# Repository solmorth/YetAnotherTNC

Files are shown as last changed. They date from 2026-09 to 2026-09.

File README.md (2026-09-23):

# YetAnotherTNC

Zephyr firmware (and, eventually, a companion PCB) for a nRF52840 Pro Micro
board that turns a phone's Bluetooth connection into a packet radio TNC.
Depending on how three GPIO pins are strapped at boot, the board acts as a
transparent UART↔BLE bridge, a real AX.25/KISS TNC driving 1200 baud Bell 202
AFSK audio (with optional FX.25 FEC), an AX.25 digipeater, or a standalone GPS
APRS tracker that beacons its position with no phone attached.

> **Early stage.** This has not been widely field-tested — one unit rides in
> the author's car and works there, but it hasn't been validated across
> different radios, conditions, or by other users. Treat it as a hobby
> project that works, not a hardened product.

No app or phone-side code lives in this repo — this is the board (and PCB)
side only. Anything that speaks BLE Nordic UART Service (NUS) and either raw
KISS or TNC2 monitor lines can talk to it; see [Phone app](#phone-app) below.

## Contents

- [Why](#why)
- [Hardware](#hardware)
  - [PCB](#pcb)
  - [Pinout](#pinout)
  - [Transceiver connector (JST 10-pin)](#transceiver-connector-jst-10-pin)
  - [Bill of Materials (BOM)](#bill-of-materials-bom)
- [Operating modes](#operating-modes)
- [Runtime configuration](#runtime-configuration)
- [Known limitations](#known-limitations)
- [Phone app](#phone-app)
- [Building](#building)
  - [Releases](#releases)
- [Testing](#testing)
- [Hardware-in-the-loop (HIL) test plan](#hardware-in-the-loop-hil-test-plan)
- [Repo layout](#repo-layout)
- [License](#license)

## Why

Cheap handheld radios generally don't have a KISS/TNC mode, and dedicated TNC
hardware is either bulky or costs more than the radio. This is a ~$10 nRF52840
board wired to a radio's mic/speaker/PTT lines, doing the AFSK modem and
AX.25 framing in software, with a phone or laptop over BLE instead of a serial
cable.

## Hardware

**Primary target: Yaesu FTM510.** The board's connector is designed to match
the FTM510's mic/data jack. The **FTM400 works out of the box** — same
connector, same signals. Any other radio that can be driven by its
mic/speaker/PTT lines can work too, via a custom audio interface cable
(not covered by this repo — just the pins on the nRF52840 side).

Board: Pro Micro nRF52840 (or any nice!nano-bootloader-compatible clone,
`promicro_nrf52840` in Zephyr).

### PCB

PCB design files and bill of materials live under [`pcb/`](pcb/) (`yatnc.kicad_sch`, `yatnc.kicad_pcb`, `yatnc.csv`).

| PCB 3D Render | PCB Editor |
|:---:|:---:|
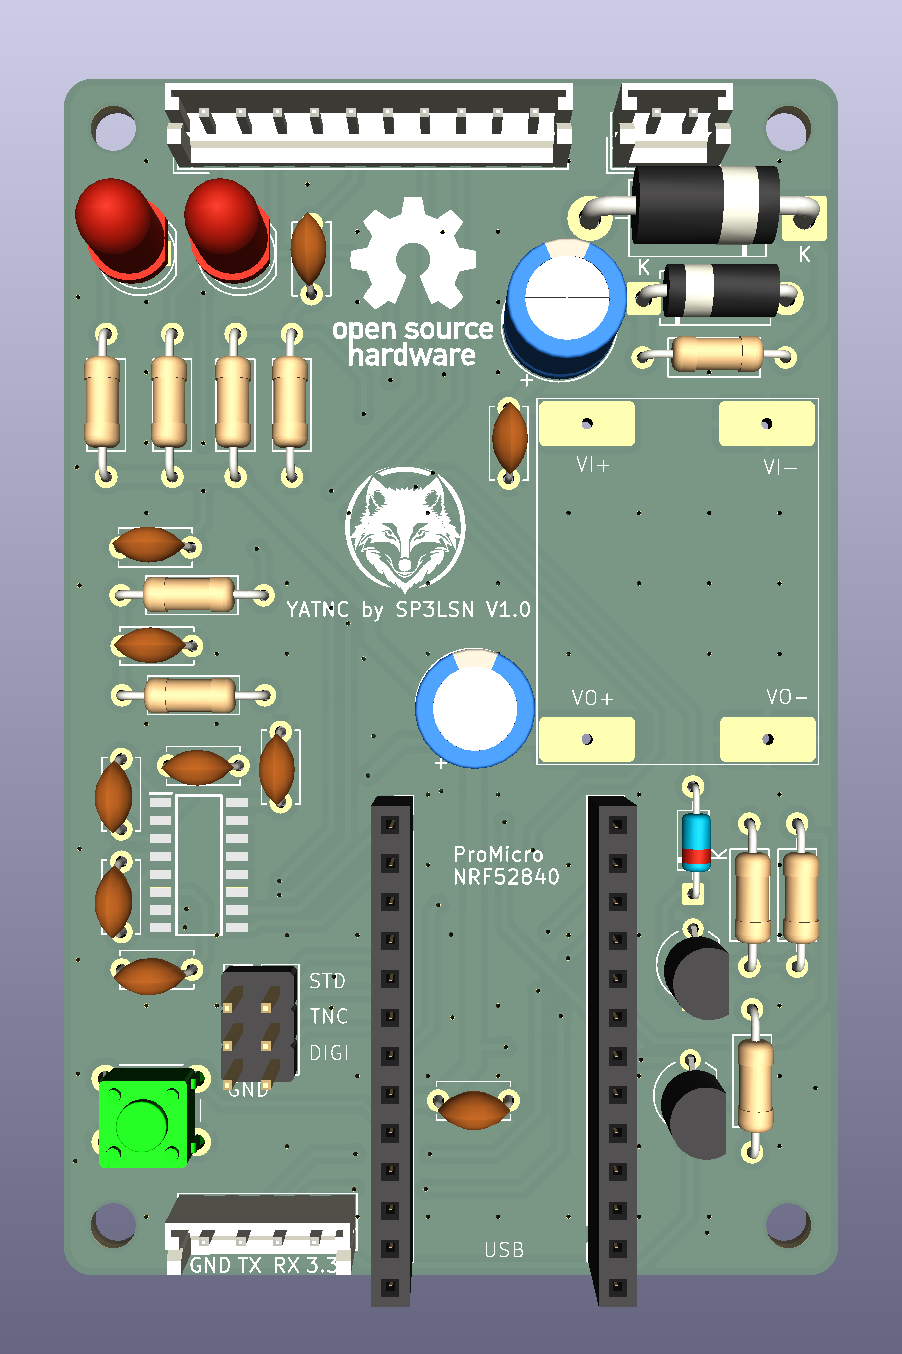
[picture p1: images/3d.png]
PCB 3D Render
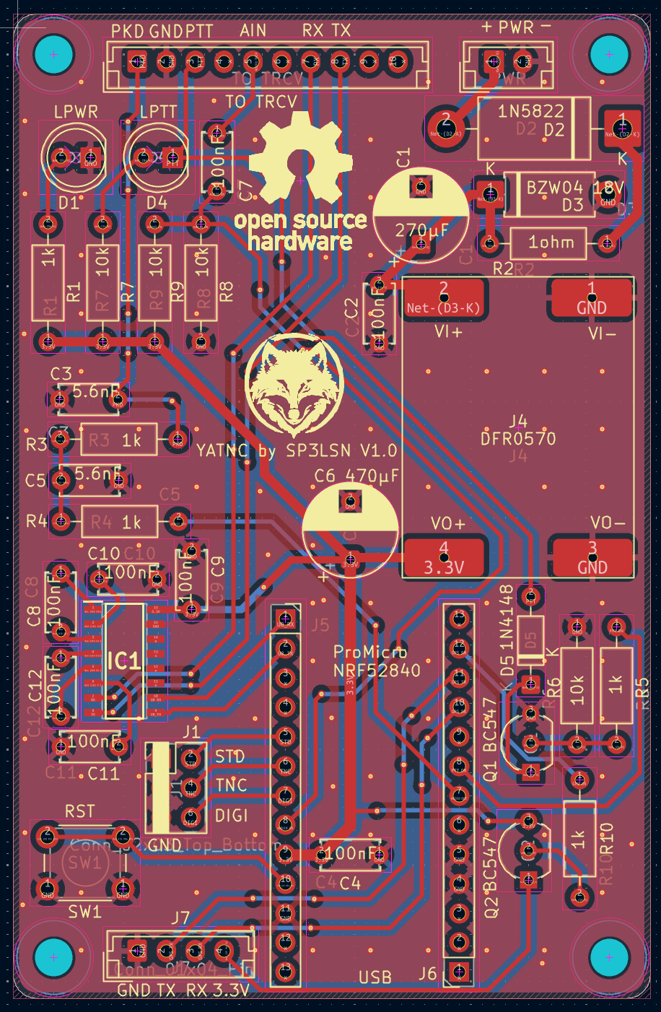
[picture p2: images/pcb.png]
PCB Editor
|  |  |

### Pinout

| Pin | DT node | Function | Notes |
|---|---|---|---|
| 9, 10 (P0.09/P0.10) | `uart0` | Radio RS232 (APRS data) | Level-shifted through an onboard MAX3232 to true RS-232 (±12V). Primary use: the FTM510/FTM400's own built-in APRS packet decoder outputs RS232 here in BRIDGE mode. Also works with other serial-speaking radios/modems that expect a native protocol. Never touched by firmware for anything else. |
| 31 (P0.31) | `zephyr,user` io-channel | RX audio in | ADC (AIN7), sampled at 9600 Hz for the AFSK demodulator. |
| 20 (P0.20) | `&pwm0_default` | TX audio out | Hardware PWM carrier, low-pass filtered externally into an analog tone. |
| 22 (P0.22) | `ptt_pin` | PTT out | Active-high. |
| 2 (P0.02) | `mode_pin` | Mode select | Pull-up, active-low. Grounded → PACKET_TNC. |
| 29 (P0.29) | `digi_pin` | Digipeater select | Pull-up, active-low. Grounded → DIGIPEATER (overrides pin 2). |
| P1.15 | `standalone_pin` | Standalone GPS select | Pull-up, active-low. Grounded → STANDALONE (overrides pins 2 and 29). |
| P0.11 / P1.00 | `uart1` | GPS NMEA in | 9600 baud, TX / RX respectively (the GPS module's RX / TX). Only used in STANDALONE mode. |
| P1.04 | `gps_enable_pin` | GPS power enable | Active-high, pulled down. Driven high at boot in STANDALONE mode (unless a fixed position is configured). |

### Transceiver connector (JST 10-pin)

> [!IMPORTANT]
> - **RS-232 voltage levels (±12V)**: The serial lines on the 10-pin JST connector (`TO TRCV`) are true **RS-232 (±12V)** driven by the onboard MAX3232 transceiver, **not** 3.3V or 5V TTL. Do not connect them directly to logic-level UART pins!
> - **RX / TX crossover**: The RS-232 RX and TX lines **must be crossed** between the board's 10-pin JST connector and the radio (Board TX &rarr; Radio RX, Board RX &rarr; Radio TX).

| Pin | Net | Function / Description |
|:---:|---|---|
| 1 | `PKD` | TX Packet Audio (from PWM filter) |
| 2 | `GND` | Ground |
| 3 | `PTT` | PTT output |
| 4 | NC | Unconnected |
| 5 | `AUDIO TRCV` | RX Audio (to ADC demodulator) |
| 6 | NC | Unconnected |
| 7 | `RX` | RS-232 RX (±12V, connect to Radio TX — **crossed**) |
| 8 | `TX` | RS-232 TX (±12V, connect to Radio RX — **crossed**) |
| 9 | NC | Unconnected |
| 10 | NC | Unconnected |

### Bill of Materials (BOM)

Generated from KiCad BOM ([`pcb/yatnc.csv`](pcb/yatnc.csv)):

| Designator | Value / Part | Qty | Description |
|---|---|:---:|---|
| C1 | 270µF 35V | 1 | Polarized electrolytic capacitor |
| C2, C4, C7, C8, C9, C10, C11, C12 | 100nF | 8 | Ceramic disc capacitor |
| C3, C5 | 5.6nF | 2 | Ceramic disc capacitor |
| C6 | 470µF 10V | 1 | Polarized electrolytic capacitor |
| D1 | LPWR | 1 | Power indicator LED (5mm) |
| D2 | 1N5822 | 1 | Schottky diode (3A, 40V) |
| D3 | BZW04 18V | 1 | TVS transient voltage suppressor diode |
| D4 | LPTT | 1 | PTT indicator LED (5mm) |
| D5 | 1N4148 | 1 | High-speed switching diode |
| IC1 | MAX3232CDR | 1 | 3.3V/5V RS-232 transceiver (SOIC-16) |
| J1 | Conn_02x03_Top_Bottom | 1 | 2×3 pin header (2.54mm pitch) |
| J4 | DFR0570 | 1 | DFRobot DFR0570 DC-DC buck converter module |
| J5, J6 | Conn_01x13_Socket | 2 | 1×13 female socket headers (for Pro Micro nRF52840) |
| J7 | Conn_01x04_Pin | 1 | JST-EH 4-pin vertical header (2.50mm pitch) |
| PWR | Conn_01x02_Socket | 1 | JST-EH 2-pin vertical power connector (2.50mm pitch) |
| Q1, Q2 | BC547 | 2 | NPN bipolar junction transistor (TO-92) |
| R1, R3, R4, R5, R10 | 1k | 5 | Axial resistor 1kΩ (DIN0207) |
| R2 | 1ohm | 1 | Axial resistor 1Ω (DIN0207) |
| R6, R7, R8, R9 | 10k | 4 | Axial resistor 10kΩ (DIN0207) |
| SW1 | RST | 1 | Tactile push button switch (6mm) |
| TO TRCV | JST | 1 | JST-EH 10-pin vertical connector (to transceiver) |

### Transceiver connector (JST 10-pin)

> [!IMPORTANT]
> - **RS-232 voltage levels (±12V)**: The serial lines on the 10-pin JST connector (`TO TRCV`) are true **RS-232 (±12V)** driven by the onboard MAX3232 transceiver, **not** 3.3V or 5V TTL. Do not connect them directly to logic-level UART pins!
> - **RX / TX crossover**: The RS-232 RX and TX lines **must be crossed** between the board's 10-pin JST connector and the radio (Board TX &rarr; Radio RX, Board RX &rarr; Radio TX).

| Pin | Net | Function / Description |
|:---:|---|---|
| 1 | `PKD` | TX Packet Audio (from PWM filter) |
| 2 | `GND` | Ground |
| 3 | `PTT` | PTT output |
| 4 | NC | Unconnected |
| 5 | `AUDIO TRCV` | RX Audio (to ADC demodulator) |
| 6 | NC | Unconnected |
| 7 | `RX` | RS-232 RX (±12V, connect to Radio TX — **crossed**) |
| 8 | `TX` | RS-232 TX (±12V, connect to Radio RX — **crossed**) |
| 9 | NC | Unconnected |
| 10 | NC | Unconnected |

### Bill of Materials (BOM)

Generated from KiCad BOM ([`pcb/yatnc.csv`](pcb/yatnc.csv)):

| Designator | Value / Part | Qty | Description |
|---|---|:---:|---|
| C1 | 270µF 35V | 1 | Polarized electrolytic capacitor |
| C2, C4, C7, C8, C9, C10, C11, C12 | 100nF | 8 | Ceramic disc capacitor |
| C3, C5 | 5.6nF | 2 | Ceramic disc capacitor |
| C6 | 470µF 10V | 1 | Polarized electrolytic capacitor |
| D1 | LPWR | 1 | Power indicator LED (5mm) |
| D2 | 1N5822 | 1 | Schottky diode (3A, 40V) |
| D3 | BZW04 18V | 1 | TVS transient voltage suppressor diode |
| D4 | LPTT | 1 | PTT indicator LED (5mm) |
| D5 | 1N4148 | 1 | High-speed switching diode |
| IC1 | MAX3232CDR | 1 | 3.3V/5V RS-232 transceiver (SOIC-16) |
| J1 | Conn_02x03_Top_Bottom | 1 | 2×3 pin header (2.54mm pitch) |
| J4 | DFR0570 | 1 | DFRobot DFR0570 DC-DC buck converter module |
| J5, J6 | Conn_01x13_Socket | 2 | 1×13 female socket headers (for Pro Micro nRF52840) |
| J7 | Conn_01x04_Pin | 1 | JST-EH 4-pin vertical header (2.50mm pitch) |
| PWR | Conn_01x02_Socket | 1 | JST-EH 2-pin vertical power connector (2.50mm pitch) |
| Q1, Q2 | BC547 | 2 | NPN bipolar junction transistor (TO-92) |
| R1, R3, R4, R5, R10 | 1k | 5 | Axial resistor 1kΩ (DIN0207) |
| R2 | 1ohm | 1 | Axial resistor 1Ω (DIN0207) |
| R6, R7, R8, R9 | 10k | 4 | Axial resistor 10kΩ (DIN0207) |
| SW1 | RST | 1 | Tactile push button switch (6mm) |
| TO TRCV | JST | 1 | JST-EH 10-pin vertical connector (to transceiver) |

## Operating modes

The firmware selects one of four modes at boot (and re-checks live on every
packet) by reading the mode-select, digipeater-select and standalone-select pins above. There is
no software switch — the mode is purely hardware-strapped, and the pins are
read fresh on every packet, so mode can in principle change at runtime by
re-wiring the straps (no latching).

Resolution order (`mode_select_get_current()` in `src/mode_select.c`):

1. `standalone_pin` grounded → **STANDALONE**
2. else `digi_pin` grounded → **DIGIPEATER**
3. else `mode_pin` grounded → **PACKET_TNC**
4. else (all floating/high, the default) → **BRIDGE**

### 1. BRIDGE (default — all pins open)

A transparent, byte-for-byte serial bridge between the radio's RS232 (UART0)
and the phone app over BLE (NUS). No AX.25/KISS parsing, no AFSK, no PTT —
just raw bytes both directions.

This is primarily for **FTM510/FTM400 radios in their own native APRS
mode**: the radio decodes AFSK itself and emits packets over RS232, and this
mode just relays that (and any outgoing data) to/from the phone app. It also
works with any other radio/modem that expects to speak its own native serial
protocol (AT commands, firmware passthrough, etc.) rather than doing AX.25
packet radio in this firmware.

- **Radio → App**: `uart_isr` (main.c) collects UART0 RX bytes into a ring
  buffer; 50ms after the line goes idle, `process_uart_to_ble()` sends
  whatever accumulated straight out over BLE notify.
- **App → Radio**: `nus_received()` queues whatever the app wrote straight to
  the TX queue; the TX thread writes it byte-by-byte to UART0 via
  `uart_poll_out()`.

### 2. PACKET_TNC (`mode_pin` grounded)

A real AX.25 KISS TNC. The app talks AX.25/KISS over BLE; the radio side is
driven as 1200 baud Bell 202 AFSK audio (with optional FX.25 forward error
correction), not raw serial.

**App → Radio (TX)**, in `tnc_process_ble_bytes()`:

1. Bytes from BLE are fed into a persistent KISS decoder. A full KISS frame
   (`FEND ... FEND`) is only acted on once its closing `FEND` has actually
   arrived — a frame split across several BLE writes (common: phones write
   in ~20-byte ATT chunks before MTU negotiation) is reassembled correctly
   before anything is sent.
2. Most phone APRS apps don't actually KISS-frame anything — they write a
   human-readable **TNC2 monitor line** instead, e.g.
   `SP3LSN-9>APVEC0,WIDE1-1,WIDE2-1:!5227.76N/01654.03E>comment`. If nothing
   KISS-decodes within 250ms of the app going idle, `tnc_send_raw_frame()`
   tries `ax25_parse_monitor()` on the accumulated bytes; on success it
   builds a real binary AX.25 UI frame (proper shifted-ASCII addresses,
   control/PID, FCS) instead of transmitting the raw text. If it doesn't
   parse either way, the bytes are assumed to already be a raw AX.25 frame
   and sent as-is.
3. If a stray `FEND` byte appears in non-KISS app data (e.g. a Latin-1
   accented character in an APRS comment happens to be `0xC0`) and never
   gets a matching closing `FEND`, the KISS decoder used to wedge itself
   in-frame forever, silently swallowing everything after it. It now
   self-resets after the same 250ms idle window instead.
4. Every queued frame is picked up by the TX thread: PTT keys (pin 22,
   active-high), the frame is modulated to AFSK PCM (`AFSKModulator`, with
   FX.25 RS(255,239) wrapping if enabled via `audio_tx_set_fx25(true)` —
   off by default, no live control path wired to it yet), the waveform is
   played out on pin 20 via the nRF52840's hardware PWM, then PTT unkeys.

**Radio → App (RX)**, two independent sources feed the same BLE output:

- **Audio demodulation**: a dedicated thread samples pin 31 (ADC, AIN7) at
  9600Hz through `AFSKDemodulator` (bandpass filter → frequency discriminator
  → DPLL bit recovery → HDLC flag/destuff, with an FX.25 correlation-tag
  correlator running in parallel that transparently Reed-Solomon-corrects a
  frame if the sender wrapped it in FX.25). A decoded frame is KISS-wrapped
  and sent over BLE.
- **UART0**: if the radio/modem itself emits KISS bytes over serial rather
  than raw audio, `tnc_process_radio_bytes()` decodes and forwards those the
  same way.

### 3. DIGIPEATER (`digi_pin` grounded, overrides `mode_pin`)

Everything PACKET_TNC does, plus: every frame heard on the radio is checked
for an un-repeated `WIDEn-N`/`DIGI` hop in its path
(`digipeat_process_frame()`). If found, the hop's SSID is decremented (H-bit
set once it reaches 0, marking it used) and the frame is re-encoded and
re-transmitted back out over radio — a standard WIDEn-N digipeater. The frame
is forwarded to the BLE app either way, repeated or not, so the app sees
everything heard on the channel.

### 4. STANDALONE (`standalone_pin` grounded, overrides the other two)

A GPS APRS tracker. The board beacons its position over the radio on a timer,
with no phone needed. Otherwise it behaves like PACKET_TNC (the BLE app can
still connect, send frames, and change [settings](#runtime-configuration)).

- **Live GPS** (default): at boot the firmware powers the GPS module
  (`gps_enable_pin`) and reads NMEA from `uart1`. `$GPGGA`/`$GNGGA` sentences
  are parsed for fix state and position. The first fix starts the beacon; it
  then repeats every `BEACON` seconds while the fix is held, using the most
  recent position. No fix (or fix lost) → nothing is transmitted.
- **Fixed position**: with `SET FIXEDPOS=ON` (and both `LAT`/`LON` set) the
  GPS module is never powered or touched. The stored coordinates are beaconed
  on the same interval, starting once the TX pipeline is up. Handy indoors or
  with no GPS fitted. Until both coordinates are set, nothing is sent.
- **Beacon format**: an uncompressed APRS position report (`!DDMM.hhN/DDDMM.hhE>` + comment)
  from your callsign to `APRS`, primary-table car symbol (`/>`), sent through the
  normal TX path (PTT → AFSK → PWM).

## Runtime configuration

Callsign, beacon interval, comment and fixed position are set at runtime with
single-line ASCII commands sent as KISS command `0x06` (`KISS_CMD_SETHARDWARE`)
over BLE. Each command is applied immediately, saved to flash, and answered
with a KISS `0x06` frame carrying the reply text. Errors are reported in the
reply (`ERR ...`), never as a dropped connection. Settings survive reboots.

| Command | Effect | Default |
|---|---|---|
| `SET CALL=N0CALL-9` | Source callsign for beacons | `N0CALL` |
| `SET BEACON=120` | Beacon interval in seconds (clamped to 10–3600) | `60` |
| `SET COMMENT=text` | Beacon comment (truncated to 32 chars) | empty |
| `SET FIXEDPOS=ON\|OFF` | Beacon a stored position instead of using GPS | `OFF` |
| `SET LAT=52.4627` / `SET LON=16.9005` | Fixed position, decimal degrees | unset |
| `GET` | Reply with all current values | |

The settings live in a 32 KiB NVS partition at `0x90000` (see `app.overlay`),
deliberately clear of the UF2 bootloader. The BLE device name is `YATNC`.

## Known limitations

- **AFSK decode is functional but not polished.** It works, but weak-signal
  / low-level decode robustness needs more work — expect some missed frames
  on marginal audio until the demodulator gets more tuning.
- **Not widely field-tested.** Verified on the bench and in one car; not yet
  validated across multiple radios, RF conditions, or users.
- FX.25 TX wrapping has no live control path yet (`audio_tx_set_fx25`, code
  only).
- STANDALONE mode parses GGA sentences only, with no altitude, speed/course or
  compressed positions in the beacon. The symbol is fixed to the car icon.
- The `SET`/`GET` config commands are not yet exposed in any phone app; send
  them yourself as KISS `0x06` frames.

## Phone app

Developed and tested against **[aprsvector](https://aprsvector.ores.one)**
(also by the author) — that's the reference app for this firmware and the
one to reach for first.

More generally, anything that speaks BLE Nordic UART Service (NUS) and
either raw KISS or TNC2 monitor lines *should* work (most Android APRS apps
fit this description), but only aprsvector has actually been tested against
this firmware.

## Building

```sh
./build.sh
```

First run creates a `.venv`, pulls a Zephyr workspace into `zephyrproject/`
(via `west`), and builds for `promicro_nrf52840`. Later runs reuse both, so
they're much faster. Pass anything after the script name straight through to
`west build` if you need non-default args:

```sh
./build.sh -b promicro_nrf52840 --pristine
```

If no usable Zephyr SDK is found (it looks in `.zephyr-sdk/`,
`~/zephyr-sdk-*`, `/opt/zephyr-sdk-*`, etc, and checks that CMake and the ARM
compiler are actually present), the script downloads a minimal one into
`.zephyr-sdk/` and sets up the `arm-zephyr-eabi` toolchain. Set
`ZEPHYR_SDK_INSTALL_DIR` to use your own instead.

Output is `build/zephyr/zephyr.uf2`. To flash: double-tap the board's reset
button to drop into the UF2 bootloader (it'll show up as a USB drive), then
copy the file over. Boards need the nice!nano / Adafruit UF2 bootloader
already installed.

### Releases

Pushing a version tag (`1.2.3` or `v1.2.3`) triggers
`.github/workflows/release.yml`, which runs the host tests, builds the
firmware, and publishes a GitHub release with `yatnc-<tag>.uf2` attached, so
you can flash without building.

```sh
git tag 1.2.3 && git push origin 1.2.3
```

## Testing

```sh
./run_tests.sh
```

Builds and runs the host-side unit tests for everything that doesn't touch
Zephyr or real hardware — AX.25, KISS, FX.25, GPS/NMEA formatting, and the AFSK modem DSP — and
fails if line coverage on any of those drops below 80%. `tnc.c`, `main.c`,
`ptt.c`, `mode_select.c`, `gps.c`, `tnc_config.c`, and the audio drivers aren't covered here; they need
a board, see [HIL test plan](#hardware-in-the-loop-hil-test-plan).

There's also a Python reference model of the AFSK modem
(`tools/afsk_dsp.py`, tested by `tools/test_afsk.py`/`pytest`) used to
sanity-check the C++ implementation and to generate/analyze WAV captures
independent of the firmware.

## Hardware-in-the-loop (HIL) test plan

`run_tests.sh` covers the Zephyr-free pure-logic modules (AX.25, KISS, FX.25,
GPS formatting, AFSK modem DSP) at ≥80% line coverage on host. It cannot touch anything that
only exists on real silicon: GPIO strapping, hardware PWM audio out, ADC
audio in, UART timing, or BLE NUS. Those need the actual `promicro_nrf52840`
board. This is a plan, not a runnable suite yet — no board rig is set up for
automated HIL runs.

What each untestable-on-host module needs:

1. **`mode_select.c`** — ground/float P0.02, P0.29 and P1.15 in each
   combination, reboot, confirm `mode_select_get_current()`/boot log report
   BRIDGE / PACKET_TNC / DIGIPEATER / STANDALONE correctly, and that re-strapping is
   picked up live (no latching).
2. **`ptt.c`** — scope P0.22 across a TX; confirm it goes active-high only
   for the duration `audio_tx_pwm` is actually playing samples, and idles
   low the rest of the time (a PTT stuck high keys the radio permanently).
3. **`audio_tx_pwm.cpp`** — scope P0.20; confirm the PWM carrier frequency
   and the external low-pass filter actually pass 1200/2200 Hz clean and
   knock the PWM carrier down enough that an external TNC (or this board's
   own RX path, looped back) decodes it.
4. **`audio_rx_adc.cpp`** — feed a known AFSK signal into P0.31 (from a
   signal generator, or TX pin of a second unit looped back through the
   filter) and confirm frames make it out over BLE.
5. **RS232 bridge (BRIDGE mode, `main.c`)** — with a real FTM510/FTM400 (or
   other serial device) on P0.09/P0.10 through the onboard MAX3232, confirm
   byte-for-byte passthrough both directions and the 50ms idle-flush timing.
6. **BLE NUS end-to-end** — a phone/PC BLE client sends a KISS frame or
   TNC2 monitor line; confirm it comes out the radio side per the routing
   already unit-tested at the `ax25.c`/`kiss.c` level, and vice versa.
7. **`gps.c`** — in STANDALONE mode with a GPS module on P0.11/P1.00, confirm
   P1.04 goes high at boot, NMEA shows in the log, and a beacon goes out
   after the first fix and again every `BEACON` seconds. With
   `FIXEDPOS=ON`, confirm P1.04 stays low and the stored position beacons.
8. **`tnc_config.c`** — send each `SET`/`GET` command over BLE, confirm the
   reply, power-cycle, and confirm values persist. Confirm the UF2 bootloader
   still works afterwards (NVS must not touch it).
9. **Full loop**: two boards, one PACKET_TNC and one DIGIPEATER, over actual
   RF or a dummy-load/attenuator link — confirms the whole AFSK+FX.25+KISS
   stack end to end, not just each half in isolation on host.

Implementing an automated HIL rig (e.g. Zephyr `twister --hardware-map`) is a
follow-up once there's dedicated bench hardware for it; for now these are run
by hand.

## Repo layout

```
src/            firmware source (Zephyr app)
tools/          host-side Python tooling (AFSK reference model, WAV decoder, log capture)
app.overlay     devicetree overlay: GPIO straps, GPS UART/enable, ADC channel, PWM pin, NVS partition
prj.conf        Zephyr/Kconfig options
CMakeLists.txt  build target sources
build.sh        one-shot Zephyr workspace + SDK + build
run_tests.sh    host-side unit tests + coverage
.github/        CI: tag-triggered release workflow
gerber/         PCB fabrication files
pcb/            KiCad board design files and BOM (yatnc.kicad_sch, yatnc.kicad_pcb, yatnc.csv)
images/         PCB 3D render and layout editor screenshots
```

Other tools in `tools/`:

- `decode_aprs.py` — decodes AX.25/APRS frames out of a captured WAV file, for checking a TX recording without a second TNC.
- `capture_log.ps1` — tails the board's USB serial console to a timestamped log file, reconnecting automatically across board resets (handy for catching a crash dump).

## License

`src/main.c` carries an `SPDX-License-Identifier: Apache-2.0` header; treat
the rest of the firmware the same way unless noted otherwise.

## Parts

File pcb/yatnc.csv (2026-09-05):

Id | Designator | Footprint | Quantity | Designation | Supplier and ref
1 | C1 | CP_Radial_D8.0mm_P5.00mm | 1 | 270µF
2 | C2, C4, C7, C8, C9, C10, C11, C12 | C_Disc_D5.0mm_W2.5mm_P5.00mm | 8 | 100nF
3 | C3, C5 | C_Disc_D5.0mm_W2.5mm_P5.00mm | 2 | 5.6nF
4 | C6 | CP_Radial_D8.0mm_P5.00mm | 1 | 470µF
5 | D1 | LED_D5.0mm | 1 | LPWR
6 | D2 | D_DO-201AD_P15.24mm_Horizontal | 1 | 1N5822
7 | D3 | D_DO-15_P10.16mm_Horizontal | 1 | BZW04 18V
8 | D4 | LED_D5.0mm | 1 | LPTT
9 | D5 | D_DO-35_SOD27_P7.62mm_Horizontal | 1 | 1N4148
10 | IC1 | SOIC127P600X175-16N | 1 | MAX3232CDR
11 | J1 | PinHeader_2x03_P2.54mm_Vertical | 1 | Conn_02x03_Top_Bottom
12 | J4 | dfr0570 | 1 | DFR0570
13 | J5, J6 | PinSocket_1x13_P2.54mm_Vertical | 2 | Conn_01x13_Socket
14 | J7 | JST_EH_B4B-EH-A_1x04_P2.50mm_Vertical | 1 | Conn_01x04_Pin
15 | PWR | JST_EH_B2B-EH-A_1x02_P2.50mm_Vertical | 1 | Conn_01x02_Socket
16 | Q1, Q2 | TO-92_Inline_Wide | 2 | BC547
17 | R1, R3, R4, R5, R10 | R_Axial_DIN0207_L6.3mm_D2.5mm_P10.16mm_Horizontal | 5 | 1k
18 | R2 | R_Axial_DIN0207_L6.3mm_D2.5mm_P10.16mm_Horizontal | 1 | 1ohm
19 | R6, R7, R8, R9 | R_Axial_DIN0207_L6.3mm_D2.5mm_P10.16mm_Horizontal | 4 | 10k
20 | SW1 | SW_PUSH_6mm | 1 | RST
21 | TO TRCV | JST_EH_B10B-EH-A_1x10_P2.50mm_Vertical | 1 | JST

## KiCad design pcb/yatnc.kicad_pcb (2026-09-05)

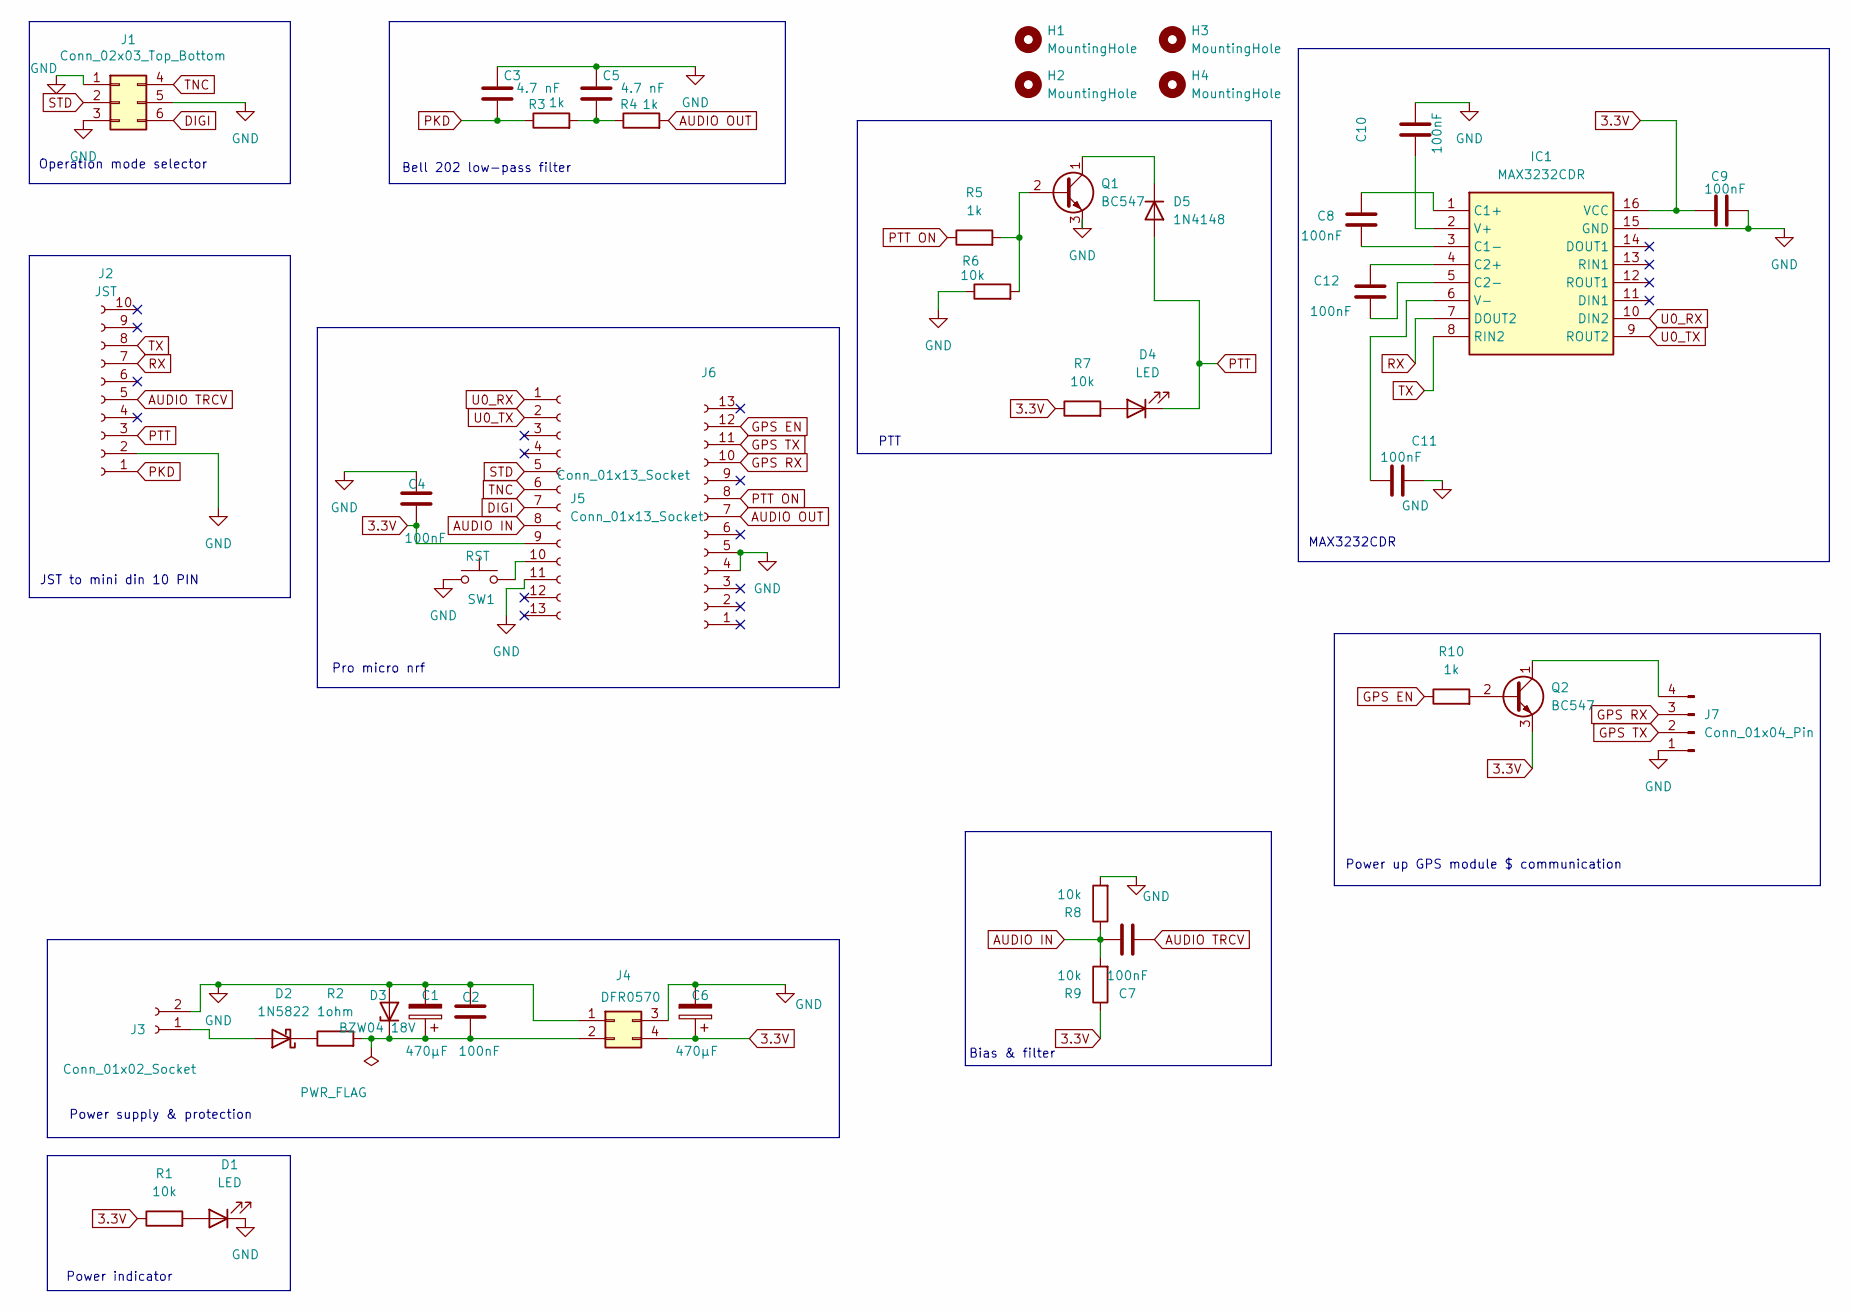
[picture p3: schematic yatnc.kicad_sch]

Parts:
C1, C6: 470µF; CP_Radial_D8.0mm_P5.00mm
C2, C4, C7, C8, C9, C10, C11, C12: 100nF; C_Disc_D5.0mm_W2.5mm_P5.00mm
C3, C5: 4.7 nF; C_Disc_D5.0mm_W2.5mm_P5.00mm
D1, D4: LED; LED_D5.0mm
D2: 1N5822; D_DO-201AD_P15.24mm_Horizontal
D3: BZW04 18V; D_DO-15_P10.16mm_Horizontal
D5: 1N4148; D_DO-35_SOD27_P7.62mm_Horizontal
H1, H2, H3, H4: MountingHole; MountingHole_3.2mm_M3
IC1: MAX3232CDR; SOIC127P600X175-16N; Mouser Part Number 595-MAX3232CDR
J1: Conn_02x03_Top_Bottom; PinHeader_2x03_P2.54mm_Vertical
J2: JST; JST_EH_B10B-EH-A_1x10_P2.50mm_Vertical
J3: Conn_01x02_Socket; JST_EH_B2B-EH-A_1x02_P2.50mm_Vertical
J4: DFR0570; dfr0570
J5, J6: Conn_01x13_Socket; PinSocket_1x13_P2.54mm_Vertical
J7: Conn_01x04_Pin; JST_EH_B4B-EH-A_1x04_P2.50mm_Vertical
Q1, Q2: BC547; TO-92_Inline_Wide
R1, R6, R7, R8, R9: 10k; R_Axial_DIN0207_L6.3mm_D2.5mm_P10.16mm_Horizontal
R2: 1ohm; R_Axial_DIN0207_L6.3mm_D2.5mm_P10.16mm_Horizontal
R3, R4, R5, R10: 1k; R_Axial_DIN0207_L6.3mm_D2.5mm_P10.16mm_Horizontal
SW1: RST; SW_PUSH_6mm

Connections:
3.3V: C4.2, C6.1, C9.1, IC1.16 (VCC), J4.4, J5.9, Q2.3 (E), R1.1, R7.1, R9.1
AUDIO IN: C7.2, J5.8, R8.1, R9.2
AUDIO OUT: J6.7, R4.2
AUDIO TRCV: C7.1, J2.5; also elsewhere on the board
DIGI: J1.6, J5.7
GND: C1.2, C2.1, C3.1, C4.1, C5.1, C6.2, C9.2, C10.2, C11.1, D1.1 (K), D3.2 (A), IC1.15 (GND), J1.1, J1.3, J1.5, J2.2, J3.2, J4.1, J4.3, J5.11, J6.4, J6.5, J7.1, Q1.3 (E), R6.1, R8.2, SW1.1; also elsewhere on the board
GPS EN: J6.12, R10.1
GPS RX: J6.10, J7.3
GPS TX: J6.11, J7.2
unnamed: C5.2, R3.2, R4.1
unnamed: D1.2 (A), R1.2
unnamed 11: D2.2 (A), J3.1; also elsewhere on the board
unnamed: D2.1 (K), R2.1
unnamed: C1.1, C2.2, D3.1 (K), J4.2, R2.2
unnamed: D4.2 (A), R7.2
unnamed: D5.1 (K), Q1.1 (C)
unnamed: C8.1, IC1.1 (C1+)
unnamed: C8.2, IC1.3 (C1-)
unnamed: C12.1, IC1.4 (C2+)
unnamed: C12.2, IC1.5 (C2-)
unnamed: C10.1, IC1.2 (V+)
unnamed: C11.2, IC1.6 (V-)
unnamed: J5.10, SW1.2
unnamed: J7.4, Q2.1 (C)
unnamed: Q1.2 (B), R5.2, R6.2
unnamed: Q2.2 (B), R10.2
PKD: C3.2, J2.1, R3.1; also elsewhere on the board
PTT: D4.1 (K), D5.2 (A), J2.3; also elsewhere on the board
PTT ON: J6.8, R5.1
RX: IC1.7 (DOUT2), J2.7; also elsewhere on the board
STD: J1.2, J5.5
TNC: J1.4, J5.6
TX: IC1.8 (RIN2), J2.8; also elsewhere on the board
U0_RX: IC1.10 (DIN2), J5.1
U0_TX: IC1.9 (ROUT2), J5.2

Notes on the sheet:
MAX3232CDR
Operation mode selector
Power up GPS module $ communication
Power supply & protection
Bias & filter
Power indicator
JST to mini din 10 PIN
PTT
Bell 202 low-pass filter
Pro micro nrf

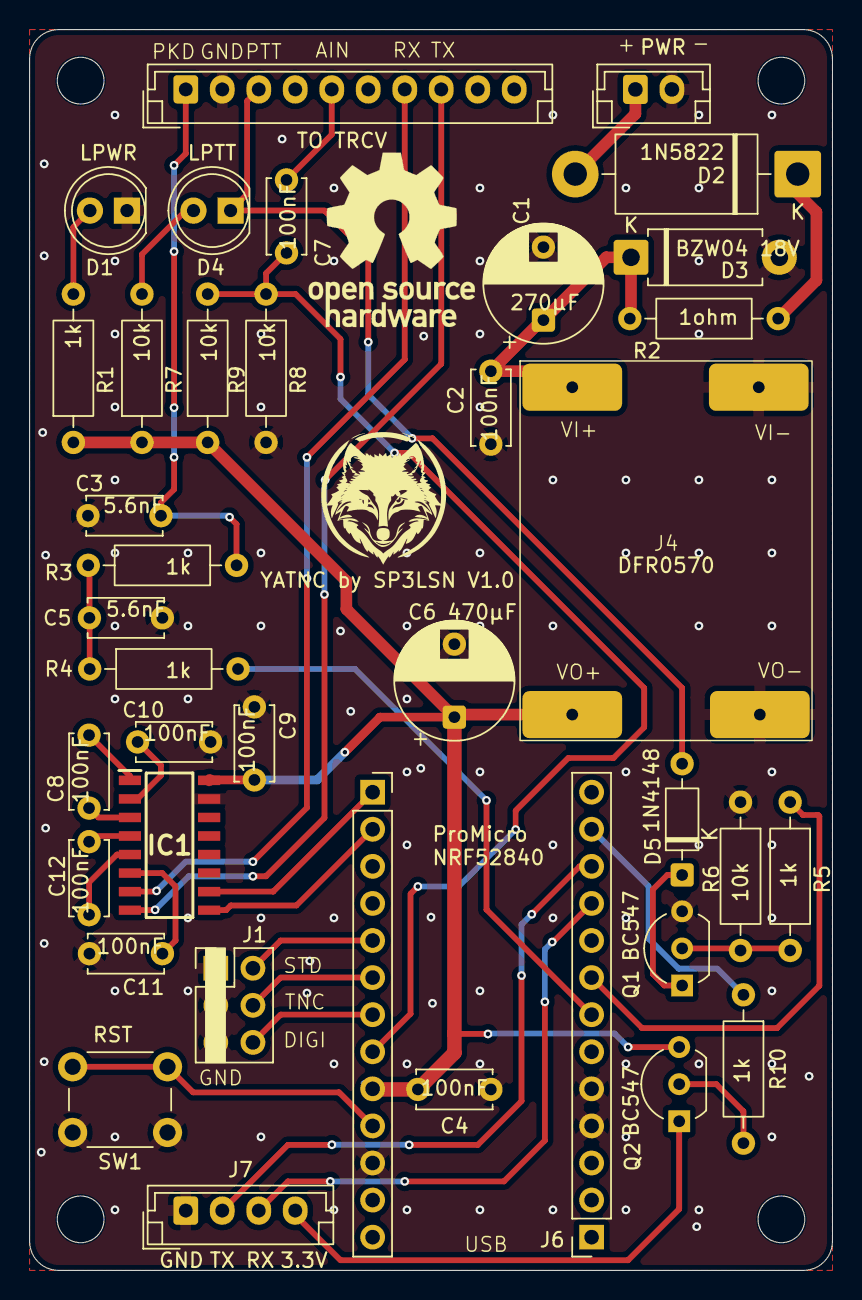
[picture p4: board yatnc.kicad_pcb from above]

Board: 2 copper layers, 55.0 x 85.0 mm, 42 parts (0 on the bottom side), 35 nets.

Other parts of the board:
PWR: Conn_01x02_Socket; JST_EH_B2B-EH-A_1x02_P2.50mm_Vertical
TO TRCV: JST; JST_EH_B10B-EH-A_1x10_P2.50mm_Vertical

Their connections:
AUDIO TRCV: TO TRCV.5; also elsewhere on the board
GND: PWR.2, TO TRCV.2; also elsewhere on the board
unnamed 11: PWR.1; also elsewhere on the board
PKD: TO TRCV.1; also elsewhere on the board
PTT: TO TRCV.3; also elsewhere on the board
RX: TO TRCV.7; also elsewhere on the board
TX: TO TRCV.8; also elsewhere on the board

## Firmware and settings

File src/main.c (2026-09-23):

/*
 * UART0 <-> BLE NUS Bridge & APRS TNC Server for ProMicro nRF52840
 *
 * SPDX-License-Identifier: Apache-2.0
 *
 * Uses interrupt-driven UART with a delayed work item for batching.
 * Supports hardware GPIO mode selection:
 *   - APP_MODE_BRIDGE: Transparent UART <-> BLE bridge (Pin High / Unbridged)
 *   - APP_MODE_PACKET_TNC: AX.25 / KISS TNC server (Pin Low / Grounded)
 *   - APP_MODE_DIGIPEATER: AX.25 Digipeater & BLE forwarding (Digi Pin Grounded)
 *
 * Console/printk goes over USB CDC ACM (configured by board DTS).
 */

#include <string.h>
#include <zephyr/kernel.h>
#include <zephyr/device.h>
#include <zephyr/drivers/uart.h>
#include <zephyr/bluetooth/bluetooth.h>
#include <zephyr/bluetooth/conn.h>
#include <zephyr/bluetooth/services/nus.h>
#include <zephyr/sys/ring_buffer.h>
#include <zephyr/version.h>

#include "mode_select.h"
#include "ptt.h"
#include "gps.h"
#include "tnc.h"
#include "ax25.h"
#include "fx25.h"
#include "kiss.h"
#include "tnc_config.h"
#include "audio_tx_pwm.hpp"
#include "audio_rx_adc.hpp"
#include "log_ts.h"

/* ---------- BLE advertising -------------------------------------------- */

#define DEVICE_NAME     CONFIG_BT_DEVICE_NAME
#define DEVICE_NAME_LEN (sizeof(DEVICE_NAME) - 1)

static const struct bt_data ad[] = {
	BT_DATA_BYTES(BT_DATA_FLAGS, (BT_LE_AD_GENERAL | BT_LE_AD_NO_BREDR)),
	BT_DATA(BT_DATA_NAME_COMPLETE, DEVICE_NAME, DEVICE_NAME_LEN),
};

static const struct bt_data sd[] = {
	BT_DATA_BYTES(BT_DATA_UUID128_ALL, BT_UUID_NUS_SRV_VAL),
};

/* ---------- UART ------------------------------------------------------- */

#define UART_NODE DT_CHOSEN(zephyr_nus_uart)
static const struct device *const uart_dev = DEVICE_DT_GET(UART_NODE);

#define RING_BUF_SIZE 1024
RING_BUF_DECLARE(uart_ring_buf, RING_BUF_SIZE);

/*
 * Delayed work: scheduled 50 ms after last received byte.
 * When it fires, the UART line has been idle for 50 ms → full message ready.
 */
static void uart_flush_work_handler(struct k_work *work);
static K_WORK_DELAYABLE_DEFINE(uart_flush_work, uart_flush_work_handler);

#define UART_IDLE_TIMEOUT_MS 50

/* ---------- Forward declarations --------------------------------------- */
static int process_uart_to_ble(void);

/* ---------- UART ISR --------------------------------------------------- */

/* printk() is not IRQ-safe on the USB CDC ACM console backend used here -
 * it can block waiting on the USB stack, which never completes from inside
 * an ISR and freezes the whole system (no fault, no reset, everything
 * including the tick just stops). Count drops here; report them from
 * uart_flush_work_handler() instead, which runs in thread context.
 */
static atomic_t uart_dropped_bytes = ATOMIC_INIT(0);

static void uart_isr(const struct device *dev, void *user_data)
{
	ARG_UNUSED(user_data);

	uart_irq_update(dev);

	if (uart_irq_rx_ready(dev)) {
		uint8_t buf[64];
		int len;

		while ((len = uart_fifo_read(dev, buf, sizeof(buf))) > 0) {
			uint32_t put = ring_buf_put(&uart_ring_buf, buf, len);
			if (put < (uint32_t)len) {
				atomic_add(&uart_dropped_bytes, (atomic_val_t)(len - (int)put));
			}
		}

		/*
		 * (Re)schedule the flush work 50 ms from now.
		 * Batch message when line goes quiet for 50ms.
		 */
		k_work_reschedule(&uart_flush_work, K_MSEC(UART_IDLE_TIMEOUT_MS));
	}
}

/* ---------- Flush work: sends accumulated UART data over BLE ----------- */

static void uart_flush_work_handler(struct k_work *work)
{
	ARG_UNUSED(work);

	atomic_val_t dropped = atomic_set(&uart_dropped_bytes, 0);
	if (dropped) {
		printk("Warning: UART ring buffer full, dropped %d bytes\n", (int)dropped);
	}

	process_uart_to_ble();
}

/*
 * bt_nus_send() -> bt_gatt_notify() -> bt_att_create_pdu() blocks for up to
 * BT_ATT_TIMEOUT (30s, see att.c) when the host's ATT buffer pool is
 * exhausted - i.e. whenever the BLE peer isn't draining notifications as
 * fast as we're producing them. ble_send_raw() is called straight from
 * uart_flush_work_handler on the system workqueue, which is also the only
 * thing draining uart_ring_buf - if it blocks there, UART reception stalls
 * too. Decouple: enqueue here (fast, never blocks) and let a dedicated
 * thread take the blocking hit, same pattern as tx_thread_entry/tx_msgq.
 */
#define BLE_TX_ITEM_MAX_LEN 512
#define BLE_TX_MSGQ_DEPTH 16

struct ble_tx_item {
	uint8_t data[BLE_TX_ITEM_MAX_LEN];
	size_t len;
};

K_MSGQ_DEFINE(ble_tx_msgq, sizeof(struct ble_tx_item), BLE_TX_MSGQ_DEPTH, 4);

/* Ref'd in ble_connected(), unref'd in ble_disconnected() - see below. */
static struct bt_conn *active_conn;

static void ble_tx_thread_entry(void *p1, void *p2, void *p3)
{
	ARG_UNUSED(p1);
	ARG_UNUSED(p2);
	ARG_UNUSED(p3);

	struct ble_tx_item item;
	int consecutive_fail = 0;

	k_thread_name_set(k_current_get(), "ble_tx");

	while (1) {
		k_msgq_get(&ble_tx_msgq, &item, K_FOREVER);

		int err = bt_nus_send(NULL, item.data, item.len);
		if (err) {
			if (err == -ENOTCONN) {
				printk("  (no BLE peer)\n");
				consecutive_fail = 0;
			} else {
				/* bt_att_create_pdu() blocks up to 30s per call when the
				 * peer isn't draining notifications fast enough, then
				 * fails with -ENOMEM - this thread would otherwise grind
				 * at ~1 item/30s forever while ble_send_raw() drops
				 * everything else as "queue full". Two in a row means the
				 * link is wedged, not just slow: force a disconnect so
				 * the peer (or a fresh one) gets a clean reconnect and
				 * the ATT buffer pool has a chance to recover.
				 */
				printk("  bt_nus_send err %d (%d in a row)\n", err, ++consecutive_fail);
				if (consecutive_fail >= 2 && active_conn) {
					printk("BLE TX stuck, forcing disconnect to recover\n");
					bt_conn_disconnect(active_conn, BT_HCI_ERR_REMOTE_USER_TERM_CONN);
					consecutive_fail = 0;
				}
			}
		} else {
			consecutive_fail = 0;
		}
	}
}

/* 1024 was tight for a thread that calls into bt_nus_send()/bt_gatt_notify()
 * on top of its own 520-byte struct ble_tx_item local - bumped as a
 * precaution alongside the system workqueue stack overflow fix (see
 * CONFIG_SYSTEM_WORKQUEUE_STACK_SIZE in prj.conf).
 */
#define BLE_TX_THREAD_STACK_SIZE 2048
#define BLE_TX_THREAD_PRIORITY 7

K_THREAD_DEFINE(ble_tx_thread_id, BLE_TX_THREAD_STACK_SIZE, ble_tx_thread_entry,
		 NULL, NULL, NULL, BLE_TX_THREAD_PRIORITY, 0, 0);

static int ble_send_raw(const uint8_t *data, size_t len)
{
	if (data == NULL || len == 0 || len > BLE_TX_ITEM_MAX_LEN) {
		return -EINVAL;
	}

	struct ble_tx_item item;
	item.len = len;
	memcpy(item.data, data, len);

	int err = k_msgq_put(&ble_tx_msgq, &item, K_NO_WAIT);
	if (err) {
		printk("Warning: BLE TX queue full, dropped notification of %d bytes\n", (int)len);
	}
	return err;
}

static int process_uart_to_ble(void)
{
	uint8_t data[247]; /* max ATT payload */
	int len;

	app_mode_t mode = mode_select_get_current();

	while ((len = ring_buf_get(&uart_ring_buf, data, sizeof(data))) > 0) {
		if (mode == APP_MODE_BRIDGE) {
			printk("UART -> BLE (Bridge): %d bytes\n", len);
			ble_send_raw(data, len);
		} else {
			printk("UART -> TNC Engine (%s): %d bytes\n", mode_select_get_name(mode), len);
			tnc_process_radio_bytes(data, len, mode, uart_dev, ble_send_raw);
		}
	}

	return 0;
}

/* ---------- BLE NUS callbacks ------------------------------------------ */

static void nus_notif_enabled(bool enabled, void *ctx)
{
	ARG_UNUSED(ctx);
	printk("BLE Notifications %s\n", enabled ? "Enabled" : "Disabled");
}

static void nus_received(struct bt_conn *conn, const void *data,
			 uint16_t len, void *ctx)
{
	ARG_UNUSED(conn);
	ARG_UNUSED(ctx);

	app_mode_t mode = mode_select_get_current();

	if (mode == APP_MODE_BRIDGE) {
		printk("BLE -> UART (Bridge): %d bytes\n", len);
		tnc_queue_tx_packet((const uint8_t *)data, len, mode);
	} else {
		printk("BLE -> TNC Engine (%s): %d bytes\n", mode_select_get_name(mode), len);
		tnc_process_ble_bytes((const uint8_t *)data, len, mode, uart_dev, ble_send_raw);
	}
}

static struct bt_nus_cb nus_listener = {
	.notif_enabled = nus_notif_enabled,
	.received      = nus_received,
};

/* ---------- BLE connection callbacks (re-advertise on disconnect) ------ */

static void ble_connected(struct bt_conn *conn, uint8_t err)
{
	if (err) {
		printk("BLE Connect failed (err %u)\n", err);
		return;
	}
	printk("BLE Connected\n");
	active_conn = bt_conn_ref(conn);
}

/*
 * Restarting advertising is deferred to the system workqueue instead of
 * calling bt_le_adv_start() straight from the disconnected callback: the
 * connection object for the link that just dropped isn't necessarily
 * released yet at that point, and starting connectable advertising before
 * it is can fail (observed as bt_le_adv_start() returning -12/-ENOMEM,
 * "no more connection objects available"). Deferring gives the stack a
 * chance to finish tearing down the old connection first.
 */
static void adv_restart_work_handler(struct k_work *work)
{
	ARG_UNUSED(work);

	int err = bt_le_adv_start(BT_LE_ADV_CONN_FAST_1, ad, ARRAY_SIZE(ad), sd, ARRAY_SIZE(sd));
	if (err) {
		printk("Failed to restart advertising: %d\n", err);
	} else {
		printk("Advertising restarted\n");
	}
}
static K_WORK_DEFINE(adv_restart_work, adv_restart_work_handler);

static void ble_disconnected(struct bt_conn *conn, uint8_t reason)
{
	ARG_UNUSED(conn);
	printk("BLE Disconnected (reason 0x%02X), restarting advertising\n", reason);

	if (active_conn) {
		bt_conn_unref(active_conn);
		active_conn = NULL;
	}

	k_work_submit(&adv_restart_work);
}

static struct bt_conn_cb conn_callbacks = {
	.connected    = ble_connected,
	.disconnected = ble_disconnected,
};

/* ---------- Console banner (deferred until a terminal is attached) ----- */

/*
 * CONFIG_BOOT_BANNER is off (see prj.conf) because the normal Zephyr version
 * banner prints before main() even runs - long before a USB CDC ACM terminal
 * has enumerated and opened the port, so it's just dropped. Re-print it (and
 * the hardware mode) from a low-priority thread that polls DTR instead of
 * blocking main() / BLE / UART bring-up on a terminal ever connecting.
 */
static void console_banner_thread_entry(void *p1, void *p2, void *p3)
{
	ARG_UNUSED(p1);
	ARG_UNUSED(p2);
	ARG_UNUSED(p3);

	const struct device *const console_dev = DEVICE_DT_GET(DT_CHOSEN(zephyr_console));
	uint32_t dtr = 0;

	while (!dtr) {
		uart_line_ctrl_get(console_dev, UART_LINE_CTRL_DTR, &dtr);
		k_sleep(K_MSEC(100));
	}

	printk("*** Booting Zephyr OS build %s ***\n", KERNEL_VERSION_STRING);
	printk("=== UART <-> BLE NUS Bridge & APRS TNC Server ===\n");
	printk("Hardware Mode Selected: %s\n", mode_select_get_name(mode_select_get_current()));
}

K_THREAD_DEFINE(console_banner_thread_id, 1024, console_banner_thread_entry,
		 NULL, NULL, NULL, 10, 0, 0);


/* ---------- main ------------------------------------------------------- */

int main(void)
{
	int err;

	printk("=== UART <-> BLE NUS Bridge & APRS TNC Server ===\n");

	mode_select_init();
	tnc_config_init();
	ptt_init();

	bool standalone_fixed_pos = mode_select_get_current() == APP_MODE_STANDALONE &&
				    tnc_config_get_fixed_pos_enabled();

	if (mode_select_get_current() == APP_MODE_STANDALONE && !standalone_fixed_pos) {
		gps_init();
		gps_enable_set(true);
	}

	tnc_init();
	fx25_init();
	printk("FX.25 FEC Engine Initialized (RS(255,239), Tag_01 0x%016llX)\n",
	       (unsigned long long)FX25_TAG_01);
	audio_tx_pwm_init();
	/* TEMPORARY bring-up aid: plain 1200Hz tone on every boot, no BLE/KISS
	 * needed - remove once the PWM DAC -> RC filter -> radio chain is
	 * confirmed working end to end.
	 */
	// audio_tx_pwm_test_tone();
	audio_rx_adc_init(ble_send_raw);

	if (!device_is_ready(uart_dev)) {
		printk("ERROR: UART device not ready\n");
	} else {
		tnc_tx_queue_init(uart_dev);
	}

	/* Only now that tnc_init()/fx25_init()/audio_tx_pwm_init()/
	 * tnc_tx_queue_init() have all run is the TX pipeline actually ready
	 * to carry a frame. gps_start_fixed_position_beacon() can fire the
	 * beacon work item with K_NO_WAIT, so starting it any earlier races
	 * the still-uninitialized PWM/DAC TX hardware - unlike the live-GPS
	 * path above, which can't queue a beacon until a real fix arrives,
	 * long after boot finishes.
	 */
	if (standalone_fixed_pos) {
		gps_start_fixed_position_beacon();
	}

	/* ---- BLE init (first, so device is always discoverable) ------- */
	err = bt_nus_cb_register(&nus_listener, NULL);
	if (err) {
		printk("Failed to register NUS callback: %d\n", err);
		return err;
	}

	err = bt_conn_cb_register(&conn_callbacks);
	if (err) {
		printk("Failed to register connection callbacks: %d\n", err);
		return err;
	}

	err = bt_enable(NULL);
	if (err) {
		printk("Failed to enable Bluetooth: %d\n", err);
		return err;
	}

	err = bt_le_adv_start(BT_LE_ADV_CONN_FAST_1, ad, ARRAY_SIZE(ad),
			      sd, ARRAY_SIZE(sd));
	if (err) {
		printk("Failed to start advertising: %d\n", err);
		return err;
	}

	printk("Advertising as \"%s\"\n", DEVICE_NAME);

	/* ---- UART init ------------------------------------------------ */
	if (!device_is_ready(uart_dev)) {
		printk("ERROR: UART device not ready\n");
		goto idle;
	}

	uart_irq_callback_set(uart_dev, uart_isr);
	uart_irq_rx_enable(uart_dev);

	printk("UART bridge & TNC Server active (IRQ + 50ms idle-batch)\n");

idle:
	/* Main loop */
	while (true) {
		k_sleep(K_FOREVER);
	}

	return 0;
}

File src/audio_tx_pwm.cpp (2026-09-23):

#include "audio_tx_pwm.hpp"
#include "afsk_modulator.hpp"
#include "ptt.h"
#include <cmath>
#include <zephyr/kernel.h>
#include <zephyr/drivers/pwm.h>
#include <zephyr/sys/printk.h>
#include "log_ts.h"

/*
 * TX Audio DAC: nRF52840 hardware PWM (PWM0 channel 1) drives Pin 20.
 * The peripheral free-runs a fixed-frequency carrier in hardware; this
 * code only rewrites the duty-cycle compare register once per AFSK audio
 * sample (9600 Hz). That gives a true duty-modulated pulse train at a
 * carrier far above the audio band, which an external RC low-pass on
 * Pin 20 reconstructs into the analog AFSK tone - unlike bit-banging the
 * pin directly at the sample rate, which used the audio rate itself as
 * the "carrier" and left little room for a passive filter to separate
 * ripple from signal.
 */
#define TX_PWM_NODE DT_NODELABEL(pwm0)
#define TX_PWM_CHANNEL 1

/* 16 MHz PWM clock / 256 = 62.5 kHz carrier: ~28x above the 2200 Hz space
 * tone (room for a simple RC filter to reject it) while keeping 8-bit
 * (256-step) duty resolution for the sine waveform.
 */
#define TX_PWM_PERIOD_CYCLES 256
#define TX_PWM_IDLE_PULSE (TX_PWM_PERIOD_CYCLES / 2)

#if DT_NODE_HAS_STATUS(TX_PWM_NODE, okay)
static const struct device *const tx_pwm_dev = DEVICE_DT_GET(TX_PWM_NODE);
#endif

extern "C" int audio_tx_pwm_init(void)
{
#if DT_NODE_HAS_STATUS(TX_PWM_NODE, okay)
	if (!device_is_ready(tx_pwm_dev)) {
		printk("Warning: TX Audio PWM device not ready\n");
		return -ENODEV;
	}

	/* Idle at 50% duty (centre level / silence) until a packet starts. */
	pwm_set_cycles(tx_pwm_dev, TX_PWM_CHANNEL, TX_PWM_PERIOD_CYCLES, TX_PWM_IDLE_PULSE, 0);
	printk("TX Audio Pin 20 Hardware PWM DAC initialized (ch %d, %u Hz carrier)\n",
	       TX_PWM_CHANNEL, 16000000u / TX_PWM_PERIOD_CYCLES);
#else
	printk("Warning: pwm0 DT node not available\n");
#endif
	return 0;
}

static float g_tx_gain = 0.30f; /* Default 30% amplitude (~0.99V p-p) to prevent overdriving mic input */

extern "C" void audio_tx_set_gain(float gain)
{
	if (gain < 0.01f) gain = 0.01f;
	if (gain > 1.0f) gain = 1.0f;
	g_tx_gain = gain;
	printk("TX Audio Gain set to %d%% amplitude\n", (int)(g_tx_gain * 100.0f + 0.5f));
}

extern "C" float audio_tx_get_gain(void)
{
	return g_tx_gain;
}

static bool g_tx_fx25_enabled = false; /* Opt-in: adds RS(255,239) FEC, at the cost of fixed ~1.7s/frame airtime */

extern "C" void audio_tx_set_fx25(bool enable)
{
	g_tx_fx25_enabled = enable;
	printk("TX FX.25 FEC %s\n", enable ? "enabled" : "disabled");
}

extern "C" bool audio_tx_get_fx25(void)
{
	return g_tx_fx25_enabled;
}


extern "C" void audio_tx_pwm_play_packet(const uint8_t *data, size_t len, app_mode_t mode)
{
	if (data == NULL || len == 0) {
		return;
	}

	bool ptt_needed = (mode == APP_MODE_PACKET_TNC || mode == APP_MODE_DIGIPEATER ||
			   mode == APP_MODE_STANDALONE);
	if (!ptt_needed) {
		return;
	}

	/* Every producer that queues a TX packet for this mode (ax25_encode(),
	 * or a KISS DATA payload straight off the wire) hands over a frame
	 * body with no FCS - it's a modem-only concept. AFSKModulator computes
	 * and appends the real one below, so `data`/`len` go in unmodified.
	 */

	printk("[AFSK TX] Modulating AX.25 frame (%d bytes) to 1200bps AFSK audio tones on Pin 20 (Gain: %.0f%%)...\n",
	       (int)len, (double)(g_tx_gain * 100.0f));

	AFSKModulator modulator(9600, 1200);

	std::vector<float> pcm_samples;
	if (g_tx_fx25_enabled) {
		pcm_samples = modulator.modulate_fx25_frame(data, len);
		if (pcm_samples.empty()) {
			printk("[AFSK TX] Frame too large for FX.25 RS(255,239) block - falling back to plain AX.25\n");
		} else {
			printk("[AFSK TX] Wrapped in FX.25 FEC (RS(255,239) block, 16 correctable bytes)\n");
		}
	}
	if (pcm_samples.empty()) {
		pcm_samples = modulator.modulate_frame(data, len);
	}

#if DT_NODE_HAS_STATUS(TX_PWM_NODE, okay)
	if (!device_is_ready(tx_pwm_dev)) {
		return;
	}

	printk("[AFSK TX] Playing %d PCM audio samples via 62.5kHz hardware PWM on Pin 20 (Pin 22 PTT Active-HIGH)\n",
	       (int)pcm_samples.size());

	/* 1. Key PTT (Pin 22 -> HIGH 3.3V) */
	ptt_set(true);

	/* Pre-TX Delay (50ms) */
	k_msleep(250);

	/* 2. Update the PWM duty cycle at the 9600 Hz sample rate; the
	 * hardware carries the actual carrier toggling autonomously between
	 * updates, so no per-carrier-edge CPU timing is needed.
	 *
	 * Schedule against the REAL hardware cycle counter (k_cycle_get_32(),
	 * 32.768kHz RTC on this board - ~30.5us quantization), re-read fresh
	 * every iteration, so any per-iteration overhead (pwm_set_cycles(),
	 * loop bookkeeping) self-corrects instead of silently accumulating
	 * as drift over a long frame - a prior version tracked only requested
	 * k_busy_wait() duration, which had no way to notice or compensate for
	 * that overhead and drifted worse the longer the frame ran. The actual
	 * pause still goes through k_busy_wait() (nrfx_coredep_delay_us(), true
	 * 64MHz-cycle precision) rather than a CPU-hogging spin on the coarse
	 * RTC counter.
	 */
	const uint32_t cycles_per_sec = sys_clock_hw_cycles_per_sec();
	const uint32_t start_cycle = k_cycle_get_32();

	for (size_t i = 0; i < pcm_samples.size(); i++) {
		uint32_t target_cycle = start_cycle + (uint32_t)((uint64_t)i * cycles_per_sec / 9600);
		int32_t cycles_remaining = (int32_t)(target_cycle - k_cycle_get_32());
		if (cycles_remaining > 0) {
			uint32_t wait_us = (uint32_t)((uint64_t)cycles_remaining * 1000000 / cycles_per_sec);
			k_busy_wait(wait_us);
		}

		float s = pcm_samples[i];
		/* Center-biased scaling with g_tx_gain attenuation to eliminate clipping/overdriving */
		float norm = 0.5f + (s * 0.5f * g_tx_gain);
		if (norm < 0.0f) norm = 0.0f;
		if (norm > 1.0f) norm = 1.0f;

		uint32_t pulse = (uint32_t)(norm * TX_PWM_PERIOD_CYCLES);

		pwm_set_cycles(tx_pwm_dev, TX_PWM_CHANNEL, TX_PWM_PERIOD_CYCLES, pulse, 0);
	}

	/* Ensure output settles back to centre level at end of audio stream */
	pwm_set_cycles(tx_pwm_dev, TX_PWM_CHANNEL, TX_PWM_PERIOD_CYCLES, TX_PWM_IDLE_PULSE, 0);

	/* Post-TX Delay (50ms) */
	k_msleep(250);

	/* 3. Unkey PTT (Pin 22 -> LOW 0V) */
	ptt_set(false);
#endif
}
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

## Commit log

2026-08-09 Init repository
    [yatnc.kicad_pcb, yatnc.kicad_sch]
2026-08-09 Fix DRC errors
    [yatnc.kicad_pcb, yatnc.kicad_sch]
2026-08-13 add into schema 2 stage RC filter
    [yatnc.kicad_pcb, yatnc.kicad_sch]
2026-08-15 added afsk filter and vin protection
    [yatnc.kicad_pcb, yatnc.kicad_sch]
2026-08-16 resolve ERC/DRC. add cleaning silkscreen, add component values
    [yatnc.kicad_pcb, yatnc.kicad_sch]
2026-08-16 first part of changes after review
    [yatnc.kicad_pcb, yatnc.kicad_sch]
2026-08-18 second part of changes after review
    [yatnc.kicad_pcb, yatnc.kicad_sch]
2026-08-18 added OSHW logo
    [yatnc.kicad_pcb]
2026-08-19 added GPS
    [yatnc.kicad_pcb, yatnc.kicad_sch]
2026-08-19 add logo
    [yatnc.kicad_pcb]
2026-08-23 max3232 refactor
    [yatnc.kicad_pcb, yatnc.kicad_sch]
2026-08-26 final polish before test order
    [yatnc.kicad_pcb]
2026-08-26 chore: update gitignore to include gerber files by overriding previous exclusions
2026-08-26 add gerber files
    [yatnc-B_Cu.gbr, yatnc-B_Mask.gbr, yatnc-B_Paste.gbr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]
2026-08-27 feat: implement GPS driver with hardware power control and UART interface
2026-08-27 feat: add standalone GPS mode selectable via dedicated hardware GPIO pin
2026-08-27 fix: enable pull-down resistor on GPS enable pin in device tree overlay
2026-08-27 feat: implement interrupt-driven GPS UART processing with ring buffer and deferred work to prevent blocking ISR
    [gps.c]
2026-08-31 feat: add GPS fix detection and automated APRS beaconing in standalone mode
    [audio_rx_adc.cpp, audio_tx_pwm.cpp, gps.c]
2026-09-05 small tweaks on silkscreen side, change components. update README, add bom
    [yatnc.csv, yatnc.kicad_pcb]
2026-09-08 fix: update device config, tune RX sensitivity, swap UART pins, and relocate NVS storage to avoid bootloader collision
    [audio_rx_adc.cpp]
2026-09-22 feat: add fixed position configuration and extract testable GPS formatting module
    [gps.c, main.c, tnc.c]
2026-09-23 fix: defer fixed-position beacon start until TX pipeline is ready
    [main.c]
2026-09-23 fix: BLE connection bug
    [tnc.c]
